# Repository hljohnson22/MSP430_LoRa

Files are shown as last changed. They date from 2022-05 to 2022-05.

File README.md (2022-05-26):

# MSP430_LoRa
This program is takes a temperature reading using one-wire commmunication, 
sends the reading to the LoRa board using SPI which transmits to the reciever, 
then goes into low power mode for 10 minutes.

Pin Outputs:<br />
p1.4 -> Temp sensor data line<br />
p5.2 -> Temp sensor power

p5.4 and p4.5 -> LoRa power in series
p1.5 (SCK)      -> LoRa SCK (ICSP pins)<br />
p1.6 (MISO/SOMI) -> LoRa MISO/SOMI (ICSP pins)<br />
p1.7 (MOSI/SIMO) -> LoRa MOSI/SIMO (ICSP pins)<br />
p5.1  -> LoRa D10 (chip select)<br />

Vcc = 3.3V

ICSP Pins:<br />
[]MISO | Vcc<br />
SCK | MOSI<br />
Reset | GND<br />

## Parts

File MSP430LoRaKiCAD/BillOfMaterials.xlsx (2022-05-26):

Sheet: Sheet1
Part | Qty per board | Qty for purchase | Price | Part number | Description | Info | Link
Resistor | 1 | 20 | $0.36 | 2368-SR1-0603-247-ND | RES 4.7K OHM 5% 1/16W 0603 | 4.7K | https://www.digikey.com/en/products/detail/nte-electronics-inc/SR1-0603-247/11649452
 | 4 | 20 | $0.36 | 2368-SR1-0603-233-ND | RES 3.3K OHM 5% 1/16W 0603 | 3.3K | https://www.digikey.com/en/products/detail/nte-electronics-inc/SR1-0603-233/11649457
 | 1 | 5 | $0.10 | RMCF0603FT330RCT-ND | RES 330 OHM 1% 1/10W 0603 | 330 | https://www.digikey.com/en/products/detail/stackpole-electronics-inc/RMCF0603FT330R/1760736
Capacitor | 1 | 5 | $0.21 | 1276-2897-1-ND | CAP CER 10UF 10V X5R 0805 | 10 microF | https://www.digikey.com/en/products/detail/samsung-electro-mechanics/CL21A106KPFNNWE/3888555
LoRa Module | 1 | 5 | $13.44 | RFM95W-915S2-ND | RX TXRX MODULE ISM < 1GHZ SMD |  | https://www.digikey.com/en/products/detail/rf-solutions/RFM95W-915S2/6564923
LoRa Antenna | 1 | 5 | $6.31 | 900-2161960011-ND | MOLEX LORA EXTERNAL ANTENNA_F |  | https://www.digikey.com/en/products/detail/molex/2161960011/13684011
SMA_Edgemount_Conn | 1 | 5 | $6.80 | 1292-1079-ND | CONN SMA JACK STR EDGE MNT |  | https://www.digikey.com/en/products/detail/walsin-technology-corporation/RFCON130803SF6B001/4936144
Header Pins | 2 | 5 | $1.02 | 2553-2044-2X10G00RA-ND | PCB SOCKET, DOUBLE ROW, 20 PIN, | 2x10 2.54mm | https://www.digikey.com/en/products/detail/oupiin/2044-2X10G00RA/13252034
LED | 1 | 5 | $0.44 | 475-3441-1-ND | LED GREEN DIFFUSED 0603 SMD |  | https://www.digikey.com/en/products/detail/osram-opto-semiconductors-inc/LT-Q39E-Q1OO-25-1/2793415
Terminal Screw Connector | 1 | 5 | $2.32 | 277-1976-ND | TERM BLK 3P SIDE ENT 5.08MM PCB | TERM BLK 3P SIDE ENT 5.08MM PCB | https://www.digikey.com/en/products/detail/phoenix-contact/1715857/1926192
DS18B20 | 1 | 5 | $9.95 | 1528-1592-ND | WATERPROOF DS18B20 DIGITAL TEMPE | WATERPROOF DS18B20 DIGITAL TEMPE | https://www.digikey.com/en/products/detail/adafruit-industries-llc/381/5875807
MSP430FR2355 | 1 | 5 | $15.59 | 296-50211-ND | LAUNCHPAD MSP430FR2355 EVAL BRD |  | https://www.digikey.com/en/products/detail/texas-instruments/MSP-EXP430FR2355/9491427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
Arduino wifi 1010 | 1 | 1 | $32.10 | 1050-1162-ND | ARDUINO MKR WIFI 1010 | Rx | https://www.digikey.com/en/products/detail/arduino/ABX00023/9486713
ATmega4809 series Transceiver; 802.11 b/g/n (Wi-Fi, WiFi, WLAN) Evaluation Board | 1 | 1 | $44.80 | 1050-1166-ND | ARDUINO UNO WIFI REV2 | Rx | https://www.digikey.com/en/products/detail/arduino/ABX00021/9486717
Total number boards | 1 | 5 |  | Shipping
Total price | $133.80 | $358.52 |  | digikey | 11 | 6.99
 |  |  |  | NTE electronics | 2 | 10.94
 |  |  |  | Oupiin America | 1 | 30
total Shipping |  | $47.93
Tariff |  | $17.68
sales tax |  | $23.33
total |  | $424.13

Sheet: Sheet2
Designators | Manufacturer Part Number | Value | Package
R1 | SR1-0603-247 | 4.7K | 0603
R2 | SR1-0603-233 | 3.3K | 0603
R3 | SR1-0603-233 | 3.3K | 0603
R4 | SR1-0603-233 | 3.3K | 0603
R5 | SR1-0603-233 | 3.3K | 0603
R6 | RMCF0603FT330R | 330 | 0603
C1 | CC0805MKX5R6BB106 | 10 UF | 0805
U2 | RFM95W-868S2
U3 | CON-SMA-EDGE-S
J1 | 2044-2X10G00RA
J2 | 2044-2X10G00RA
D1 | LT Q39E-Q1OO-25-1 |  | 0603
J3 | 1715857
U1 | 381

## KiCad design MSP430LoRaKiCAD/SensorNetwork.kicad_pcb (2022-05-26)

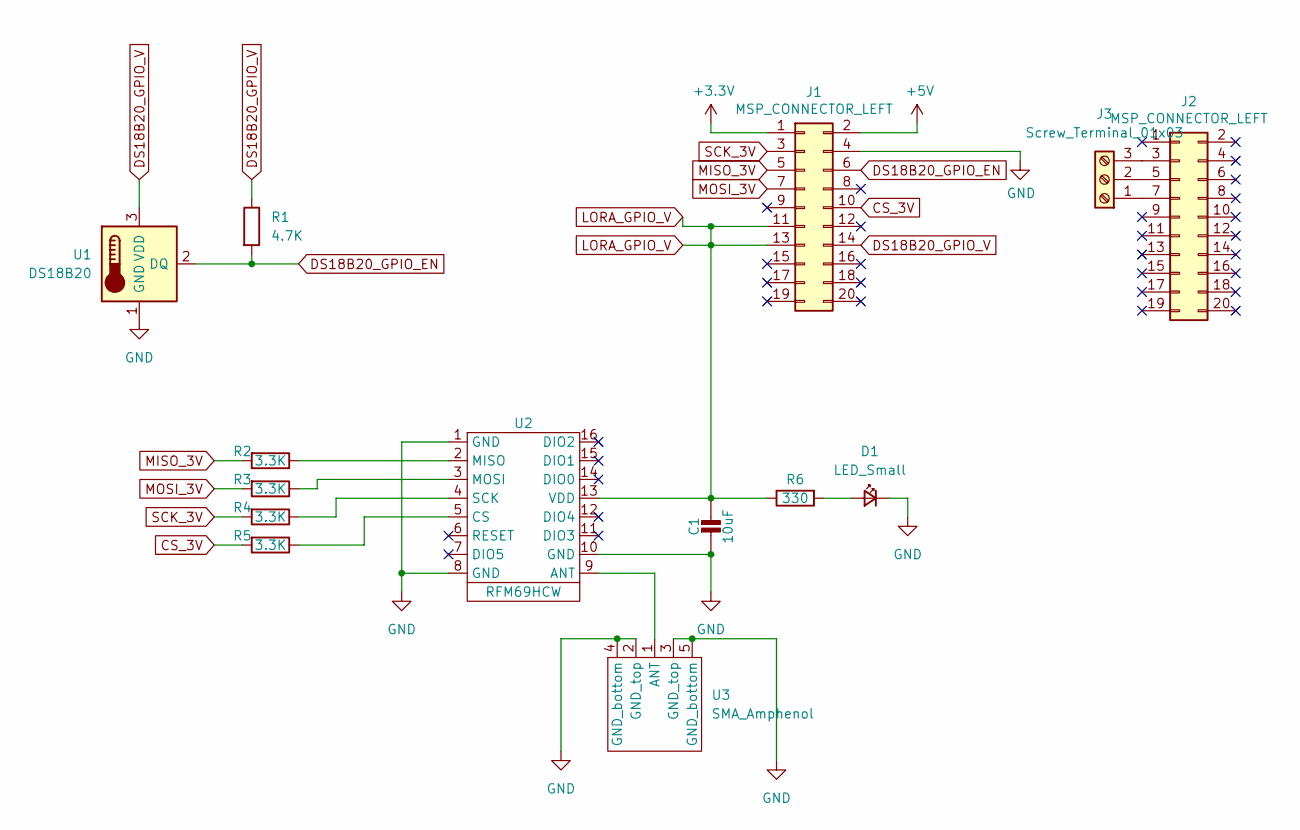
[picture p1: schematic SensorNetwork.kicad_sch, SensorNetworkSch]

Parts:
C1: 10uF; C_0805_2012Metric
D1: LED_Small; LED_0603_1608Metric
J1, J2: MSP_CONNECTOR_LEFT; PinHeader_2x10_P2.54mm_Vertical
J3: Screw_Terminal_01x03; PhoenixContact_MSTBVA_2,5_3-G-5,08_1x03_P5.08mm_Vertical
R1: 4.7K; R_0603_1608Metric
R2, R3, R4, R5: 3.3K; R_0603_1608Metric
R6: 330; R_0603_1608Metric
U1: DS18B20; TO-92_Inline
U2: RFM69HCW; LoRa_RFM
U3: SMA_Amphenol

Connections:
+3V3: J1.1
+5V: J1.2
CS_3V: J1.10, R5.2
DS18B20_GPIO_EN: J1.6, R1.2, U1.2 (DQ)
DS18B20_GPIO_V: J1.14, R1.1, U1.3 (VDD)
GND: C1.2, D1.1 (K), J1.4, U1.1 (GND), U2.1 (GND), U2.8 (GND), U2.10 (GND), U3.2 (GND_top), U3.3 (GND_top), U3.4 (GND_bottom), U3.5 (GND_bottom)
LORA_GPIO_V: C1.1, J1.11, J1.13, R6.1, U2.13 (VDD)
MISO_3V: J1.5, R2.2
MOSI_3V: J1.7, R3.2
unnamed: D1.2 (A), R6.2
unnamed: J2.3, J3.3
unnamed: J2.5, J3.2
unnamed: J2.7, J3.1
unnamed: R2.1, U2.2 (MISO)
unnamed: R3.1, U2.3 (MOSI)
unnamed: R4.1, U2.4 (SCK)
unnamed: R5.1, U2.5 (CS)
unnamed: U2.9 (ANT), U3.1 (ANT)
SCK_3V: J1.3, R4.2

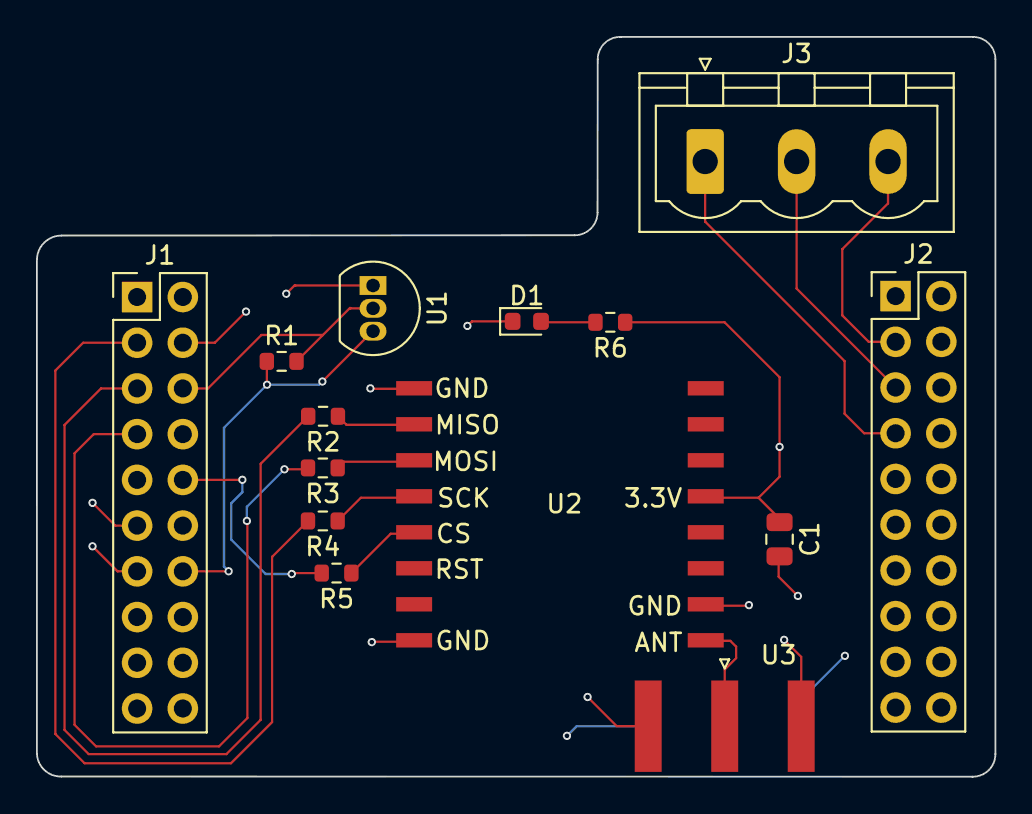
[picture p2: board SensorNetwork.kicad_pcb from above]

Board: 4 copper layers, 53.3 x 41.1 mm, 14 parts (0 on the bottom side), 17 nets.

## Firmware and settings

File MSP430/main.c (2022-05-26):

#include <msp430.h> 
#include "main.h"

bool i2c_succeed;

volatile uint8_t pulses;
/**
 * main.c
 */
int main(void)
{


    WDTCTL = WDTPW | WDTHOLD;                     // Stop watchdog timer

    // Disable the GPIO power-on default high-impedance mode to activate
    // previously configured port settings
    PM5CTL0 &= ~LOCKLPM5;

    initClockTo1MHz();

    while (1)
    {
        P1DIR |= BIT0;
        P1OUT &= ~BIT0;
        P1OUT ^= BIT0; //LED1


        P5DIR |= BIT4; //power to LoRa
        P5OUT |= BIT4;
        P4DIR |= BIT5; //in series to add current
        P4OUT |= BIT5;

        P5DIR |= BIT2; //power to sensor
        P5OUT |= BIT2;

        //temperature sensor data line
        P1OUT |= BIT4;                                  // P1.4 output high
        P1DIR |= BIT4;                                  // P1.4 as output

        __delay_cycles(1000); //needs time to get the crystal working properly

        //initialize SPI and I2C
        initGPIO_SPI();
        initSPI();
        initGPIO_I2C();
        initI2C();

        __delay_cycles(10000); //wait for initialization

        //take temp reading
        __delay_cycles(RESET_DELAY*3);

        init_DS18B20();                               // Send reset
        ROM_read();                                   // Send Read ROM command
        for (byte = 0; byte < 8; byte++)
            identification[byte] = Single_read();     // Read full identification number
        function_command_convert();                   // Send function convert temperature command

        __delay_cycles(RESET_DELAY*3);

        init_DS18B20();                               // Send reset
        ROM_read();                                   // Send Read ROM command
        for (byte = 0; byte < 8; byte++)
            identification[byte] = Single_read();     // Read full identification number
        function_command_read();                      // Send function read command
        for (byte = 0; byte < 9; byte++)
          temp[byte] = Single_read();                 // Read output from sensor


        smsbTemp = temp[1] << 4;                      //find temp MSB
        lsbTemp = temp[0] >> 4;                       //find temp lsb
        raw = smsbTemp | lsbTemp;                     //concat temp values
        decimalPlaceValue = (lsbTemp << 4) ^ temp[0]; //find decimal place value
        finalTemp[0] = raw;
        finalTemp[1] = decimalPlaceValue;

        P1OUT |= BIT4;                                //LED update for debugging

        //send over LoRa
        __delay_cycles(1000);
        while(!init_wireless());

        uint16_t CrC = add_crc(finalTemp, 2, 1);      //calculate temp CRC
        finalTemp[2] = (CrC & 0xFF00) >> 8;           //split CRC in two 8 bit variables
        finalTemp[3] = (CrC & 0x00FF);

        wireless_send(finalTemp, 4);                  //send data

        //TEST: without, should be turned off in sleep func
        //P5OUT ^= BIT4; //LoRa power off
        P1OUT ^= BIT0; //LED off
        P5OUT |= BIT4;
        P4OUT |= BIT5;
        P5OUT |= BIT2;


        sleep_10_min();                               //low power mode 4 for 10 min sleep

    }
}

// RTC interrupt service routine
#if defined(__TI_COMPILER_VERSION__) || defined(__IAR_SYSTEMS_ICC__)
#pragma vector=RTC_VECTOR
__interrupt void RTC_ISR(void)
#elif defined(__GNUC__)
void __attribute__ ((interrupt(RTC_VECTOR))) RTC_ISR (void)
#else
#error Compiler not supported!
#endif
{
    switch(__even_in_range(RTCIV,RTCIV_RTCIF))
    {
        case  RTCIV_NONE:   break;          // No interrupt
        case  RTCIV_RTCIF:                  // RTC Overflow
            RTCCTL |= RTCSR; // turn off the timer
            __bic_SR_register_on_exit(LPM4_bits);
            break;
        default: break;
    }
}

//interrupt

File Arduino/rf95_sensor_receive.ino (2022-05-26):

#include <SPI.h>
#include <RH_RF95.h>
#include <WiFiNINA_Generic.h>
#include <ArduinoJson.h>
#include <string>

#include "defines.h"
#include "arduino_secrets.h"

int SEESAW_NUM = 3;

// To eliminate FW warning when using not latest nina-fw version
// To use whenever WiFi101-FirmwareUpdater-Plugin is not sync'ed with nina-fw version
#define WIFI_FIRMWARE_LATEST_VERSION        "1.4.5"

///////please enter your sensitive data in the Secret tab/arduino_secrets.h
char ssid[] = SECRET_SSID;        // your network SSID (name)
char pass[] = SECRET_PASS;        // your network password (use for WPA, or use as key for WEP), length must be 8+

int keyIndex = 0;                 // your network key Index number (needed only for WEP)

int status = WL_IDLE_STATUS;

// if you don't want to use DNS (and reduce your sketch size)
// use the numeric IP instead of the name for the server:
char server[] = "httpbin.org";    // name address for server (using DNS)

// Initialize the Ethernet client library
// with the IP address and port of the server
// that you want to connect to (port 80 is default for HTTP):
WiFiClient client;

// Singleton instance of the radio driver
RH_RF95 rf95;

// single JSON instance we can write to over and over again
StaticJsonDocument<100> doc; // allocate on stack - we need about 100 bytes to have this working
StaticJsonDocument<100> doc_1; // allocate on stack - we need about 100 bytes to have this working

static int32_t twosComplement(int32_t val, uint8_t bits) {
  if (val & ((uint32_t)1 << (bits - 1))) {
    val -= (uint32_t)1 << bits;
  }
  return val;
}

uint16_t check_crc(uint8_t buffer[], uint16_t bufferLength, uint8_t crcType){
    uint8_t i;
    uint16_t crc;
    uint16_t polynomial;

    polynomial = (crcType == 1) ? 0xC002 : 0x8810; //0x8005 : 0x1021;
    crc = (crcType == 1) ? 0xFFFF : 0x1D0F;

    for(i = 0; i < bufferLength; i++){
      crc = ComputeCrc(crc, buffer[i], polynomial);
    }
    if(crcType == 1){
      return crc;
    }
    else{
      return (uint16_t)(~crc);
    }
}

void printWiFiStatus() 
{
  // print the SSID of the network you're attached to:
  Serial.print(F("SSID: "));
  Serial.println(WiFi.SSID());

  // print your board's IP address:
  IPAddress ip = WiFi.localIP();
  Serial.print(F("IP Address: "));
  Serial.println(ip);

  // print the received signal strength:
  long rssi = WiFi.RSSI();
  Serial.print(F("Signal strength (RSSI):"));
  Serial.print(rssi);
  Serial.println(F(" dBm"));
}

void setup() 
{
  // initialize RF95
  Serial.begin(9600);
  while (!Serial) ; // Wait for serial port to be available
  if (!rf95.init())
    Serial.println("init failed");  
  else
    Serial.println("initialization successful");

  // Initialize ESP32   ???
  Serial.begin(115200);
  while (!Serial);

  Serial.print(F("\nStart WiFiWebClient on ")); Serial.println(BOARD_NAME);
  Serial.println(WIFININA_GENERIC_VERSION);

  // check for the WiFi module:
  if (WiFi.status() == WL_NO_MODULE)
  {
    Serial.println(F("Communication with WiFi module failed!"));
    // don't continue
    while (true);
  }

  String fv = WiFi.firmwareVersion();
  if (fv < WIFI_FIRMWARE_LATEST_VERSION)
  {
    Serial.print(F("Your current firmware NINA FW v"));
    Serial.println(fv);
    Serial.print(F("Please upgrade the firmware to NINA FW v"));
    Serial.println(WIFI_FIRMWARE_LATEST_VERSION);
  }

  // attempt to connect to Wifi network:
  while (status != WL_CONNECTED)
  {
    Serial.print(F("Attempting to connect to SSID: "));
    Serial.println(ssid);
    // Connect to WPA/WPA2 network. Change this line if using open or WEP network:
    status = WiFi.begin(ssid, pass);

    // wait 10 seconds for connection:
    delay(10000);
  }

  Serial.println(F("Connected to WiFi"));
  printWiFiStatus();
}

void loop()
{
  if (rf95.available())
  {
    // Should be a message for us now   
    uint8_t buf[RH_RF95_MAX_MESSAGE_LEN];
    uint8_t len = sizeof(buf);
    if (rf95.recv(buf, &len))
    {

      /* MSP430 calaculates by
        smsbTemp = temp[1] << 4;
        lsbTemp = temp[0] >> 4;
        raw = smsbTemp | lsbTemp;
        decimalPlaceValue = (lsbTemp << 4) ^ temp[0];
        finalTemp[0] = raw;
        finalTemp[1] = decimalPlaceValue;
       */
        
       /*
        * CRC calcualted:
        uint16_t CrC = add_crc(finalTemp, 2, 1);
        finalTemp[2] = (CrC & 0xFF00) >> 8;
        finalTemp[3] = (CrC & 0x00FF);
        */
        
        /*
         * 4 bytes of data, 0 and 1 are temp, 2 and 3 is CRC
         */
      if (len == 4) { //check length of packet sent from MSP430
        uint8_t temp[2];
        temp[0] = buf[0];
        temp[1] = buf[1];
        //concat into 1 value

        uint16_t finalTemp = temp[0] << 8 //check shift
        finalTemp = finalTemp || temp[1] //check this is correct val
        
        //compute new crc
        uint16_t newCRC = check_crc(finalTemp, 2, 1)

        //concat old crc
        //concat buf[2] and buf[3] to find CRC that was calculated
        uint16_t oldCRC = buf[2] << 8
        oldCRC = oldCRC || buf[3] //check this is expected. same concat process as temp.


        if(oldCRC == newCRC){
          //   check MSB for temp[0] 1=signed, 0=unsigned
          //   decide temp value, and concat with temp[1] (which is the dedcimala place)

          if(finalTemp || )
          //serialize temp to json string
          String minif_json;
          serializeJson(doc, minif_json); // serialize object to String
          Serial.println(minif_json);
        }
        
        //else drop packet. i.e. do nothing.
      } 
      //send recieved data over wifi
      String content_length_str = "Content-Length: ";
      content_length_str += minif_json.length();

      if (client.connect(server, 80))
      {
        Serial.println(F("Connected to server"));
        // Make a HTTP request:
        client.println("POST /post HTTP/1.1");
        client.println("Host: httpbin.org");
        client.println("Accept: application/json");
        client.println("Content-Type: application/json");
        client.println(content_length_str);
        client.println(minif_json);
        client.println("Connection: close");
        client.println();

        //check wireshark to see if packets are being sent
        //should we implement a firebase version?
        
      }
      Serial.println("Done.");

      // read response body
      while (client.available())
      {
        char c = client.read();
        Serial.write(c);
      }
    
      // if the server's disconnected, stop the client:
      if (!client.connected())
      {
        Serial.println(F("\nDisconnecting from server."));
        client.stop();
      }
    }
    
    else
    {
      Serial.println("recv failed");
    }
  }
}

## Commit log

2022-04-18 Adding all files
    adding msp430 program files that reads sensor and sends data over lora.
2022-05-26 KiCAD files
    The files in the directory can be use to edit the boards, or create more.
    [BillOfMaterials.xlsx, SensorNetwork.kicad_pcb, SensorNetwork.kicad_sch]
2022-05-26 reorganizing
    Added arduino code
    reorganized repo.
